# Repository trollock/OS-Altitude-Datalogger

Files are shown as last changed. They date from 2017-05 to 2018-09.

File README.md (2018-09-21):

Note: version 3.0.0 is undergoing revision, merge of version 4.0.0 expected November 2018. It is strongly advised to await improvements in v 4.0.0.

# OS-Altitude-Datalogger
Open Source Code and Design Files for the TI MSP430FR5949 and Bosch BME280 Altitude Datalogger

The following repository contains the drivers, software, and EAGLE files to create a low power datalogger capable of recording pressure, temperature, and (with modified software) humidity. 

# About the BME280
(https://ae-bst.resource.bosch.com/media/_tech/media/datasheets/BST-BME280_DS001-11.pdf) 

# About the MSP430FR5969
The MSP430FR596 is an ultra-low power MCU capable of recording up to 64 kB of data to non-volatile FRAM memory.  FRAM (ferro-magnetic Random Access Memory) has advantages over other memory types such as flash by requiring significantly less power and faster write times.
(http://www.ti.com/product/MSP430FR5949)

# To install
Dowload this repository as a zip
Unzip file and rename to "MSP430FR5949_LP"
Locate the Folder where the Energia applicaiton is installed
Copy this folder into the following directory: /Contents/Resources/Java/hardware/msp430/variants/
Open the boards.txt file located at: /Contents/Resources/Java/hardware/msp430/ in a text editor
Append the following text at the end of the file

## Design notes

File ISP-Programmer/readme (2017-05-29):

The follwing files are for the PCB to program dataloggers on a MSP430FR5969 Launchpad vis ISP

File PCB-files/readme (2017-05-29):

The two following files are for the ordering of the most recent versions of the PCB

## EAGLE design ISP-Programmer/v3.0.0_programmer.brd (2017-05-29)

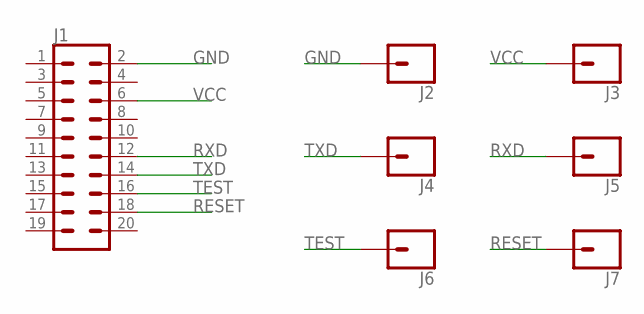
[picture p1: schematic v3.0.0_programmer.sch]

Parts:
J1: CONN_10X2NOSILK; 2X10_NOSILK
J2, J3, J4, J5, J6, J7: CONN_01; 1X01

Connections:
GND: J1.2, J2.1
RESET: J1.18, J7.1
RXD: J1.12, J5.1
TEST: J1.16, J6.1
TXD: J1.14, J4.1
VCC: J1.6, J3.1

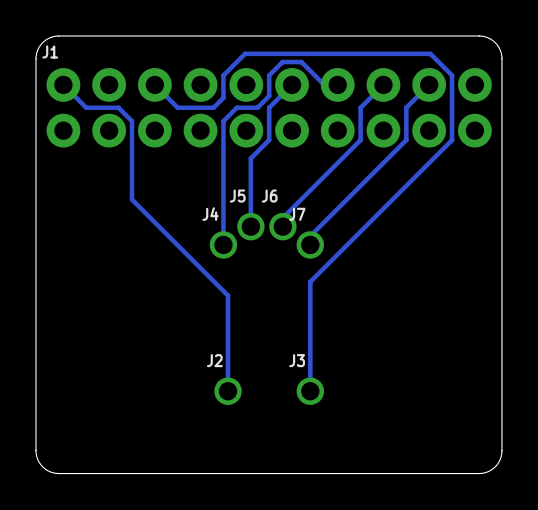
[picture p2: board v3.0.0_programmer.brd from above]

Board: 2 copper layers, 25.9 x 24.3 mm, 7 parts (0 on the bottom side), 6 nets.

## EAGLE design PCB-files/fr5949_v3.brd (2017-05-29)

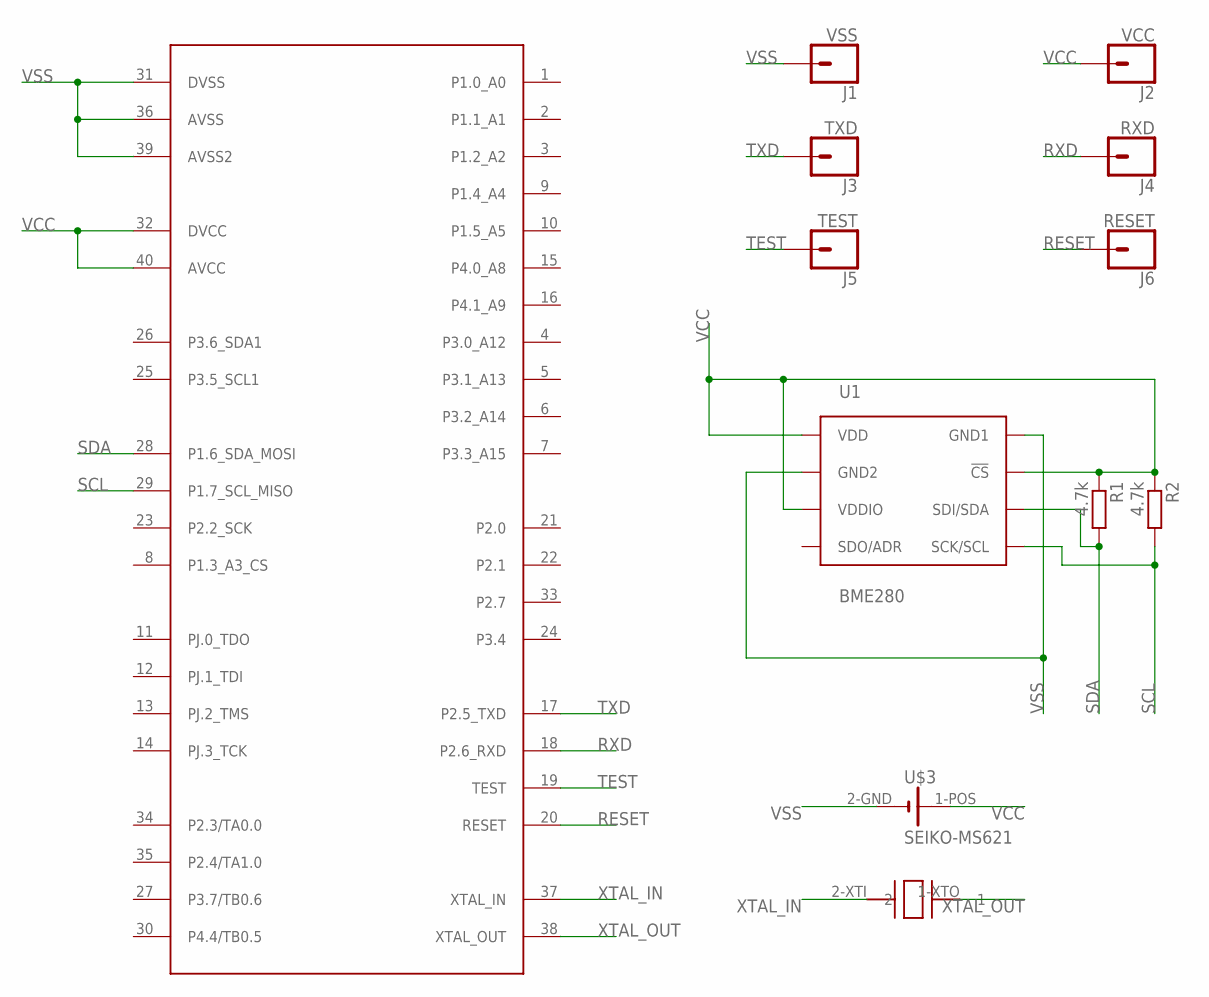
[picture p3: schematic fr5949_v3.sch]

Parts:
J1: VSS; 1X01
J2: VCC; 1X01
J3: TXD; 1X01
J4: RXD; 1X01
J5: TEST; 1X01
J6: RESET; 1X01
R1, R2: 4.7k; R0201
U1: BME280; BME280_LGA
U$1: MSP430FR5949_RHA; RHA-40-VQFN
U$2: ABS06; 2.0X1.0RTC
U$3: SEIKO-MS621; SEIKO_MICRO

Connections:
RESET: J6.1, U$1.20 (RESET)
RXD: J4.1, U$1.18 (P2.6_RXD)
SCL: R2.2, U1.P$4 (SCK/SCL), U$1.29 (P1.7_SCL_MISO)
SDA: R1.2, U1.P$3 (SDI/SDA), U$1.28 (P1.6_SDA_MOSI)
TEST: J5.1, U$1.19 (TEST)
TXD: J3.1, U$1.17 (P2.5_TXD)
VCC: J2.1, R1.1, R2.1, U1.P$2 (!CS), U1.P$6 (VDDIO), U1.P$8 (VDD), U$1.32 (DVCC), U$1.40 (AVCC), U$3.1-POS (+)
VSS: J1.1, U1.P$1 (GND1), U1.P$7 (GND2), U$1.31 (DVSS), U$1.36 (AVSS), U$1.39 (AVSS2), U$3.2-GND (-)
XTAL_IN: U$1.37 (XTAL_IN), U$2.2-XTI (2)
XTAL_OUT: U$1.38 (XTAL_OUT), U$2.1-XTO (1)

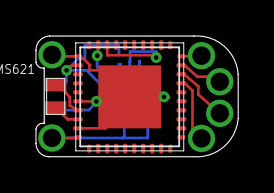
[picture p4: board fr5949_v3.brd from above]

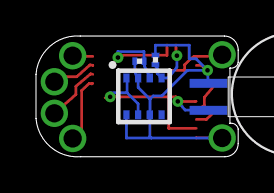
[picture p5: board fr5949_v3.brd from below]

Board: 2 copper layers, 11.2 x 6.7 mm, 12 parts (3 on the bottom side), 10 nets.

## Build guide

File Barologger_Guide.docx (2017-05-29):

# Open Source Barologger Tag

### Version 3.0.2, programmed with Energia 17

### Purpose

To provide a lightweight pressure, temperature, and humidity datalogger that is programmable using a simple, high-level language for the study of movement in small animals.

### Overview

The datalogger sensor polling, sampling rate, duty cycle, and memory allocation is managed by a microcontroller with onboard ferromagnetic memory (FRAM). FRAM has several advantages over other memory formats (e.g. FLASH, EEPROM, SRAM, etc) by using less power, is rewritable, and is non-volatile.

The pressure sensor is a microelectromechanical system (MEMS) that is controlled using an I2C interface.

The microcontroller minimizes power usage by powering down different systems when they are not necessary for operation. For example, when the datalogger isn’t gathering information from the sensor about the local environment, the only necessary operations are keeping track of the time between each sample. Thus, after gathering a sample and recording it to FRAM, the microcontroller places the sensor in sleep mode to minimize power usage and turns off other various peripheral functions of the microcontroller before placing itself in sleep mode until the next sampling.

To minimize drift and maintain accurate time intervals between samplings, the microcontroller uses an external 32.748 KHz crystal oscillator.

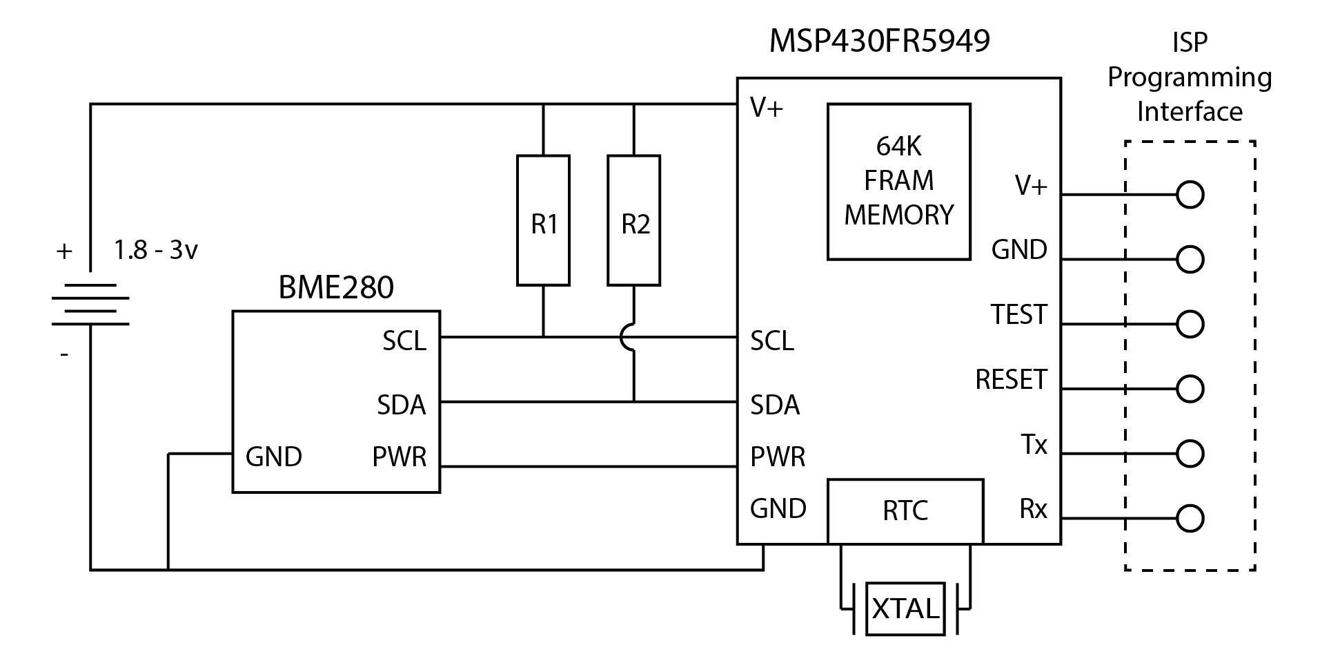
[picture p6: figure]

### Hardware

Texas Instruments MSP430FR5949

The MSP430™ ultra-low-power (ULP) FRAM platform combines uniquely embedded FRAM and a holistic ultra-low-power system architecture, allowing innovators to increase performance at lowered energy budgets. FRAM technology combines the speed, flexibility, and endurance of SRAM with the stability and reliability of flash at much lower power.

The MSP430 ULP FRAM portfolio consists of a diverse set of devices featuring FRAM, the ULP 16-bit MSP430 CPU, and intelligent peripherals targeted for various applications. The ULP architecture showcases seven low-power modes, optimized to achieve extended battery life in energy-challenged applications.

The complete datasheet can be found here (http://www.ti.com/lit/gpn/MSP430FR5949).

Bosch BME280

The BME280 is an integrated environmental sensor developed specifically for mobile applications where size and low power consumption are key design constraints. The unit combines individual high linearity, high accuracy sensors for pressure, humidity and temperature in an 8-pin metal-lid 2.5 x 2.5 x 0.93 mm³ LGA package, designed for low current consumption (3.6 μA @1Hz), long term stability and high EMC robustness.

The humidity sensor features an extremely fast response time which supports performance requirements for emerging applications such as context awareness, and high accuracy over a wide temperature range. The pressure sensor is an absolute barometric pressure sensor with features exceptionally high accuracy and resolution at very low noise. The integrated temperature sensor has been optimized for very low noise and high resolution. It is primarily used for temperature compensation of the pressure and humidity sensors, and can also be used for estimating ambient temperature.

The BME280 supports a full suite of operating modes which provides the flexibility to optimize the device for power consumption, resolution and filter performance.

The complete datasheet can be found here (https://ae-bst.resource.bosch.com/media/_tech/media/datasheets/BST-BME280_DS001-11.pdf).

### Power Consumption and Duty Cycle

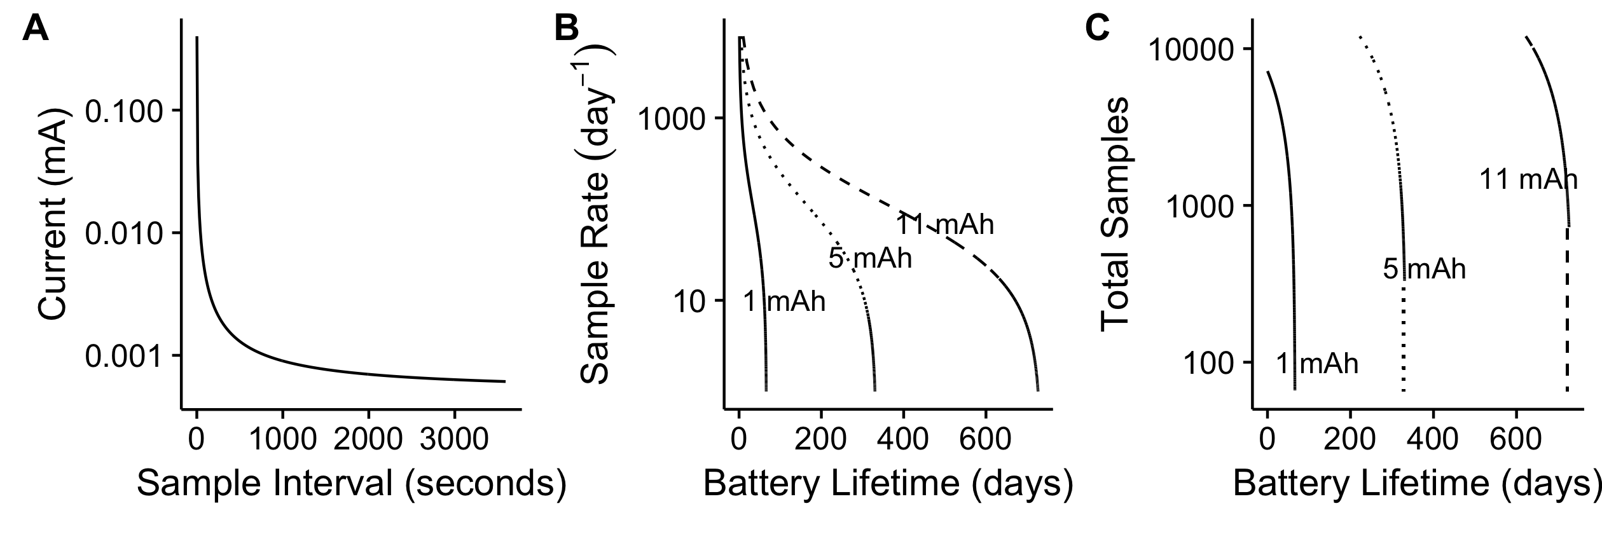
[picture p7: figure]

### Previous Versions

The following table is a list of components that were used in previous versions of the datalogger.

| | Hardware Version
Component | Type | 1.0 | 2.0 | 3.0
MSP430FR5969 | Microcontroller | • | •
MSP430FR5949 | Microcontroller | | | •
BMP180 | Sensor | •
BMP280 | Sensor | | •
BME280 | Sensor | | | •

### Libraries

The datalogger uses the following libraries to communicate with the sensor using I²C, set the appropriate registers and settings for the sensor, and to keep track of time.

BME280_MOD-1022.h links to a file

Wire.h is the default I2C library provided with Energia

RTClib.h is a library to keep track of time in common units

All library files should be placed within the Energia folder specifically for libraries. This is typically placed in the ~/User/Documents/ folder during installation as the folder ~/User/Documents/Energia/. More information detailing installation of libraries and general Energia troubleshooting can be found at the following link -

http://energia.nu/guide/library-manager/

### Demo Code

To write data into the non-volatile FRAM, variables are pre allocated into the section(“.text”) in the available memory. In the above code snippet, the number 5000 in the brackets is the number of samples. There is a limit of 64k memory including the program overhead.

The setup loop “void setup()” runs once and initializes the libraries that will be used by the microcontroller.

clockSetup(); is a local function that sets the registers for the external 32.768 kHz crystal. More data is provided below on the individual parts of the function.

setPins(); is a local function that sets the unused pins of the microcontroller to LOW to prevent pin floating and reduce power consumption during low power mode.

Wire.begin() initializes“Wire”, the library we will use to communicate with the sensor via I2C.

Serial.begin() initializes “Serial”, the library that is used for communications between the computer and the datalogger. Serial is only kept initialized during testing, and is typically used to ensure the microcontroller is reading data from the sensor correctly.

downloadData(); is a local function that provides readout of data stored on the FRAM. It has a default timeout of 15 seconds before it exits the loop and begins logging data again.

pinMode(BME280_power, OUTPUT) is setting the status of the power pin for the Bosch BME280 sensor variable, “BME280_power” as an output pin.

rtc.begin(DateTime(F(_DATE_), F(_TIME))); is from the RTC library, a function that captures local time from the PC that is programming the datalogger.

rtc.adjust(DateTime(…); is from the RTC library, a function that can adjust the set local time if there is a delay due to the compiler. Default is set at 28 seconds.

timestamp(); is a local function that records the compile time to FRAM.

The “void loop()” repeats indefinitely until the memory is full or the power source drops below operational voltage. It controls the basic functions of recording the sensor data and low power modes.

wakeUp() is a function that wakes the sensor from sleep mode.

BME280Settings() controls the basic settings of the sensor including operating mode and oversampling rate. The functions contained are provided in more detail below.

BME280.readCompensationParams() is a function that provides the onboard compensation parameters from the factory.

BME280.readMeasurements() is a function that reads the measurements from the sensor. The measurements are read in a specific order; humidity, temperature and pressure to ensure accuracy.

serialTestMode() is a function that provides serial output via terminal for troubleshooting.

gotoSleep() is a local function that sets the datalogger into low power mode.

downloadData() is a local function that provides readout of data stored on the FRAM. It has a default timeout of 15 seconds before it exits the loop and begins logging data again. Pressing any key and hitting “send” on terminal or serial monitor will enter the download loop. The variable address count increases each turn until it reaches the maximum number of samples (default = 5000) and reads out the variables stored in the FRAM across the serial terminal.

clockSetup() is a local function that sets the main clock to use the external 32.768 kHz crystal and clear faults until the oscillator is stable.

setPins() function controls the default status of the unused pins of the microcontroller. All except the Serial pins (28 and 29), I2C pins (17 and 18), and the sensor power pin (pin 1) are set LOW.

BME280Settings() function controls the basic settings of the sensor including operating mode and oversampling rate.

BME280.writeMode()

BME280.writeOversamplingPressure() controls the oversampling rate of the sensor when measuring air pressure. There are 5 settings available –

os1x is a single sample, os2x averages 2 samples, os4x averages 4 samples, os8x averages 8 samples, and os16x averages 16 samples

The oversampling rate illustrates a tradeoff between accuracy and power consumption, as os16x provides the highest sensor accuracy but is using power 16 times as long as os1x.

gotoSleep() is a local function that places the datalogger into low power mode.

deployMode() is a local function that reads the data from the sensor and writes it to the FRAM. Sample count increases each turn until the reaches the maximum set (5000 in default).

### Programming

The device can be programmed using the appropriate version of Energia listed at the top of this document. It is programmed using Inline Serial Programming (ISP) protocol coupled with either a homemade connector or the provided programmer template.

The programmer can be connected to the MSP430FR5969 Launchpad by removing the following jumpers that connect between the debugger and the target MSP430. This disables the target MCU and makes the programmer board the target.

http://43oh.com/2011/11/tutorial-to-use-your-launchpad-as-a-programmer/

We are using 6 total lines to communicate with the target datalogger using ISP, including 2 to ensure the datalogger is functioning properly (Rx and Tx for Serial communication).

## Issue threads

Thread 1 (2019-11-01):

RTC timing error / drift

trollock, 2019-11-01:
The current RTC setup on the datalogger has greater drift than originally specified.  Need to investigate in further detail what is causing this.

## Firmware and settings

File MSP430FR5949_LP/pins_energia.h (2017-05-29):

/*
  ************************************************************************
  *	pins_energia.h
  *
  *	Pin definition functions for LaunchPad w/ msp430fr5949 (originally for msp430fr5969)
  *		Copyright (c) 2012 Robert Wessels. All right reserved.
  *
  *     Contribution: Stefan Sch
  *		Modified: J. Ryan Shipley 5/4/2017
  ***********************************************************************
  Derived from:
  pins_arduino.h - Pin definition functions for Arduino
  Part of Arduino - http://www.arduino.cc/

  Copyright (c) 2007 David A. Mellis

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
  You should have received a copy of the GNU Lesser General
  Public License along with this library; if not, write to the
  Free Software Foundation, Inc., 59 Temple Place, Suite 330,
  Boston, MA  02111-1307  USA
*/

#ifndef Pins_Energia_h
#define Pins_Energia_h
#ifndef BV
#define BV(x) (1 << (x))
#endif


#if defined(__MSP430_HAS_EUSCI_B0__)
static const uint8_t SS      = 8;   /* P3.4 */
static const uint8_t SCK     = 23;   /* P2.2 */
static const uint8_t MOSI    = 28;  /* P1.6 aka SIMO */
static const uint8_t MISO    = 29;  /* P1.7 aka SOMI */
static const uint8_t TWISDA1  = 28;  /* P3.6 SW I2C - 26*/
static const uint8_t TWISCL1  = 29;   /* P3.5 SW I2C - 25 */ 
static const uint8_t TWISDA0  = 28;  /* P1.6 UCB0 */
static const uint8_t TWISCL0  = 29;  /* P1.7 UCB0 */
#define TWISDA0_SET_MODE  (PORT_SELECTION1 | INPUT_PULLUP)
#define TWISCL0_SET_MODE  (PORT_SELECTION1 | INPUT_PULLUP)
#define TWISDA1_SET_MODE  (INPUT_PULLUP)
#define TWISCL1_SET_MODE  (INPUT_PULLUP)
#define SPISCK_SET_MODE  (PORT_SELECTION1)
#define SPIMOSI_SET_MODE (PORT_SELECTION1)
#define SPIMISO_SET_MODE (PORT_SELECTION1)
/* Define the default I2C settings */
#define DEFAULT_I2C -1 /* indicates SW I2C on pseudo module 1 */
#define TWISDA TWISDA1
#define TWISCL TWISCL1
#define TWISDA_SET_MODE  TWISDA1_SET_MODE
#define TWISCL_SET_MODE  TWISCL1_SET_MODE
#endif

#if defined(__MSP430_HAS_EUSCI_A0__) || defined(__MSP430_HAS_EUSCI_A1__)
static const uint8_t DEBUG_UARTRXD = 22;  /* Receive  Data (RXD) at P2.1 */
static const uint8_t DEBUG_UARTTXD = 21;  /* Transmit Data (TXD) at P2.0 */
static const uint8_t AUX_UARTRXD = 18;     /* Receive  Data (RXD) at P4.5 */
static const uint8_t AUX_UARTTXD = 17;     /* Transmit Data (TXD) at P4.4 */
#define DEBUG_UARTRXD_SET_MODE (PORT_SELECTION1 | INPUT)
#define DEBUG_UARTTXD_SET_MODE (PORT_SELECTION1 | OUTPUT)
#define AUX_UARTRXD_SET_MODE (PORT_SELECTION1 | INPUT)
#define AUX_UARTTXD_SET_MODE (PORT_SELECTION1 | OUTPUT)
#define DEBUG_UART_MODULE_OFFSET 0x00
#define AUX_UART_MODULE_OFFSET 0x20
#define SERIAL1_AVAILABLE 1
#endif

/* Analog pins */

static const uint8_t A0  = 128 + 0; // Not available on BoosterPack header
static const uint8_t A1  = 128 + 1; // Not available on BoosterPack header
static const uint8_t A2  = 3;
static const uint8_t A3  = 8;
static const uint8_t A4  = 9;
static const uint8_t A5  = 10;
static const uint8_t A6  = 34; // Not available on BoosterPack header
static const uint8_t A7  = 37; // Not available on BoosterPack header
//static const uint8_t A8  = 23; // Available, but not on the 20-pin BP header
//static const uint8_t A9  = 24; // Available, but not on the 20-pin BP header
//static const uint8_t A10 = 128 + 10;
//static const uint8_t A11  = 5;
static const uint8_t A12  = 4; 
static const uint8_t A13  = 5;  // Not available on BoosterPack header
static const uint8_t A14  = 6; // Not available on BoosterPack header
static const uint8_t A15  = 7; // Not available on BoosterPack header


// Pin names based on the MSP430FR5949 Datasheet
//

static const uint8_t P1_0 = 1;
static const uint8_t P1_1 = 2;
static const uint8_t P1_2 = 3;
static const uint8_t P1_3 = 8;
static const uint8_t P1_4 = 9;
static const uint8_t P1_5 = 10;
static const uint8_t P1_6 = 28;
static const uint8_t P1_7 = 29;

static const uint8_t P2_0 = 21;
static const uint8_t P2_1 = 22;
static const uint8_t P2_2 = 23;
static const uint8_t P2_3 = 34;
static const uint8_t P2_4 = 35;
static const uint8_t P2_5 = 17;
static const uint8_t P2_6 = 18;
static const uint8_t P2_7 = 33;

static const uint8_t P3_0 = 4;
static const uint8_t P3_1 = 5;
static const uint8_t P3_2 = 6;
static const uint8_t P3_3 = 7;
static const uint8_t P3_4 = 24;
static const uint8_t P3_5 = 25;
static const uint8_t P3_6 = 26;
static const uint8_t P3_7 = 27;

static const uint8_t P4_0 = 15;
static const uint8_t P4_1 = 16;
//static const uint8_t P4_2 = 2;
//static const uint8_t P4_3 = 5;
static const uint8_t P4_4 = 30;
//static const uint8_t P4_5 = 27;
//static const uint8_t P4_6 = 25;
//static const uint8_t P4_7 = ;

static const uint8_t PJ_0 = 11;
static const uint8_t PJ_1 = 12;
static const uint8_t PJ_2 = 13;
static const uint8_t PJ_3 = 14;
static const uint8_t PJ_4 = 37;
static const uint8_t PJ_5 = 38;
//static const uint8_t PJ_6 = ;
//static const uint8_t PJ_7 = ;
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

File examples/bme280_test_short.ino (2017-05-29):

/*
Bosch BME 280 Open Source Sensor Tag 
Version 1.0.0 BMP_180
Version 2.0.0 Updated to smaller BMP_280 sensor *sensor is now obsolete*
Version 2.0.1 Added RTClib to include program time stamp 
Version 3.0.0 Upgraded to smaller BME_280 sensor that includes humidity measurements
*/

#include <BME280_MOD-1022.h>
#include <Wire.h>
#include "RTClib.h"

/* Variables to change related to datalogger operation schedule
--------------------------------------------------------------------------------------*/
int sampleInterval = 1;                           // time between samples in seconds


int BME280_power = 11;                           // select the pin for the BME 280 sensor
int SampleNumber = 0;
int AddressCount = 0;

// variables to keep the values
float temperature = 0;
float pressure = 0;
uint8_t humidity = 0;

__attribute__((section(".text"))) uint8_t TempStore[5000]; 
__attribute__((section(".text"))) float PresStore[5000]; 
__attribute__((section(".text"))) uint8_t HumidStore[5000]; 
__attribute__((section(".text"))) int SampleCount = 1;
__attribute__((section(".text"))) uint16_t Year = 0;
__attribute__((section(".text"))) uint8_t Month = 0;
__attribute__((section(".text"))) uint8_t Day = 0;
__attribute__((section(".text"))) uint8_t Hour = 0;
__attribute__((section(".text"))) uint8_t Minute = 0;
__attribute__((section(".text"))) uint8_t Second = 0;

RTC_Millis rtc;

void setup(){                                     // This loop only runs once at startup
  clockSetup();
  setPins();
  Wire.begin();                                  //This initializes the Wire I2C library
  Serial.begin(9600);                          //This initializes and sets the baud rate for the Serial communication
  downloadData();
  pinMode(BME280_power, OUTPUT);
  rtc.begin(DateTime(F(__DATE__), F(__TIME__))); //This grabs local time from the PC you are programming from i.e. may need adjustment depending on compilation delay
  DateTime now = rtc.now();
  rtc.adjust(DateTime(now.year(), now.month(), now.day(), now.hour(), now.minute(), now.second() + 28));
  timeStamp();
}

void loop()                                      //This is the main loop that is repeated indefinitely
{ 
  wakeUp(); 
  BME280Settings();                              //This function is below and sets the BME 280 sensor settings
  BME280.readCompensationParams();               //Read out the BME 280 parameters - must do this before calling the getxxxxx 
  delay(100);
  BME280.readMeasurements();                    //Read the pressure, temperature, and humidity measurements.  Defined in BME_280.h and BME_280.cpp
  serialTestMode();                             //Provides serial output during test mode
  deployMode();
  gotoSleep();
}

/* -----------------------------------------------------------------------------------------------------------
All functions below here are to streamline code, and control parameters for the sensor or read/write functions
------------------------------------------------------------------------------------------------------------*/
void downloadData(){
  Serial.println("Press any key and hit send within 15 seconds if you want to download data");
  unsigned long starttime = millis();
  unsigned long endtime = starttime;
  while ((endtime - starttime) <=15000){ // this is the wait time for downloads in msec
    while (Serial.available()){
      startTime();
      for (int k=1; k < SampleCount; k++){
        AddressCount = k;
        uint8_t TempOutput = TempStore[AddressCount];
        float PresOutput = PresStore[AddressCount];
        uint8_t HumidOutput = HumidStore[AddressCount];
         Serial.print(k);
         Serial.print(",");
         Serial.print(TempOutput);
         Serial.print(",");
         Serial.print(PresOutput);
         Serial.print(",");
         Serial.println(HumidOutput);
      }
      sleepSeconds(300);
    }
    int loopcount = loopcount+1;
    endtime = millis();
  }
}

void clockSetup() {
   CSCTL0_H = 0xA5;                             // CS password
   CSCTL2 |= SELM__LFXTCLK;  
   CSCTL4 &= ~LFXTOFF;                          // Turn on LFXT
   do{  
     CSCTL5 &= ~(LFXTOFFG);                     // Clear XT1 fault flag
    SFRIFG1 &= ~OFIFG;
   }while (SFRIFG1 & OFIFG);                    // Test oscillator fault flag
}

void setPins() {
       for(int i=1; i<17; i++){
    pinMode(i,OUTPUT);
    digitalWrite(i,LOW);
       }
       for(int i=21; i<28; i++){
    pinMode(i,OUTPUT);
    digitalWrite(i,LOW);
       }
 }
 
void BME280Settings() {                         //This function sets the basic oversampling registers for the BME 280 Sensor
  BME280.writeMode(smNormal);                   //Write mode, choose from (forced, normal, sleep)
  BME280.writeOversamplingPressure(os4x);       //Pressure oversampling, Choose from os1x, os2x, os4x, os8x, and os16x, osXXx is # of samples
  BME280.writeOversamplingTemperature(os4x);    //Temperature oversampling, see options above ^^
  BME280.writeOversamplingHumidity(os4x);       //Humidity oversampling, see options above ^^
}

void wakeUp() {
  digitalWrite(BME280_power, HIGH);             //Power up the peripherals from sleep mode.
  delay(50);
}

void gotoSleep(){
  BME280.writeMode(smSleep);
  Wire.endTransmission();
  digitalWrite(BME280_power, LOW);
  digitalWrite(17, LOW);
  digitalWrite(18, LOW);
  digitalWrite(28, LOW);
  digitalWrite(29, LOW);
  PAOUT = 0; PBOUT = 0; PJOUT = 0;
  PADIR = 0xFFFF; PBDIR = 0xFFFF; PJDIR = 0xFF;
  PAIFG = 0; PBIFG = 0;
  sleepSeconds(sampleInterval);
}

void timeStamp(){
  DateTime now = rtc.now();
  Year = now.year();
  Month = now.month();
  Day = now.day();
  Hour = now.hour();
  Minute = now.minute();
  Second = now.second();
}

void startTime(){
  Serial.print(Year, DEC);
  Serial.print('/');
  Serial.print(Month, DEC);
  Serial.print('/');
  Serial.print(Day, DEC);
  Serial.print(' ');
  Serial.print(Hour, DEC);
  Serial.print(':');
  Serial.print(Minute, DEC);
  Serial.print(':');
  Serial.print(Second, DEC);
  Serial.print(',');
  Serial.print("Sample Interval =");
  Serial.print(sampleInterval, DEC);
  Serial.println(" seconds");
  Serial.print("Sample");
  Serial.print(',');
  Serial.print("Temp");
  Serial.print(',');
  Serial.print("Pressure");
  Serial.print(',');
  Serial.println("Humidity");
  delay(100);
}

void serialTestMode() {                         //
  Serial.print("Temp=");
  Serial.print(BME280.getTemperature());  // must get temp first
  Serial.print(", Pressure=");
  Serial.print(BME280.getPressure());
  Serial.print(", Humidity=");
  Serial.print(BME280.getHumidity());
  Serial.print(",");
  DateTime now = rtc.now();
  Serial.print(now.year(), DEC);
  Serial.print('/');
  Serial.print(now.month(), DEC);
  Serial.print('/');
  Serial.print(now.day(), DEC);
  Serial.print(' ');
  Serial.print(now.hour(), DEC);
  Serial.print(':');
  Serial.print(now.minute(), DEC);
  Serial.print(':');
  Serial.print(now.second(), DEC);
  Serial.println();
  delay(100);
}

void deployMode() {
    temperature = BME280.getTemperature();
    pressure = BME280.getPressure();
    humidity = BME280.getHumidity();
    if (SampleCount <= 5000){
    TempStore[SampleCount] = temperature;
    PresStore[SampleCount] = pressure;
    HumidStore[SampleCount] = humidity;
    SampleCount++;
    }
}

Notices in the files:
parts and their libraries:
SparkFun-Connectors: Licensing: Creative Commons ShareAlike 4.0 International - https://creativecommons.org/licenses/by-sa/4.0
